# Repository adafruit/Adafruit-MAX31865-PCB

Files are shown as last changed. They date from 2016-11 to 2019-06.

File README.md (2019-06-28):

## Adafruit MAX31865 PCB

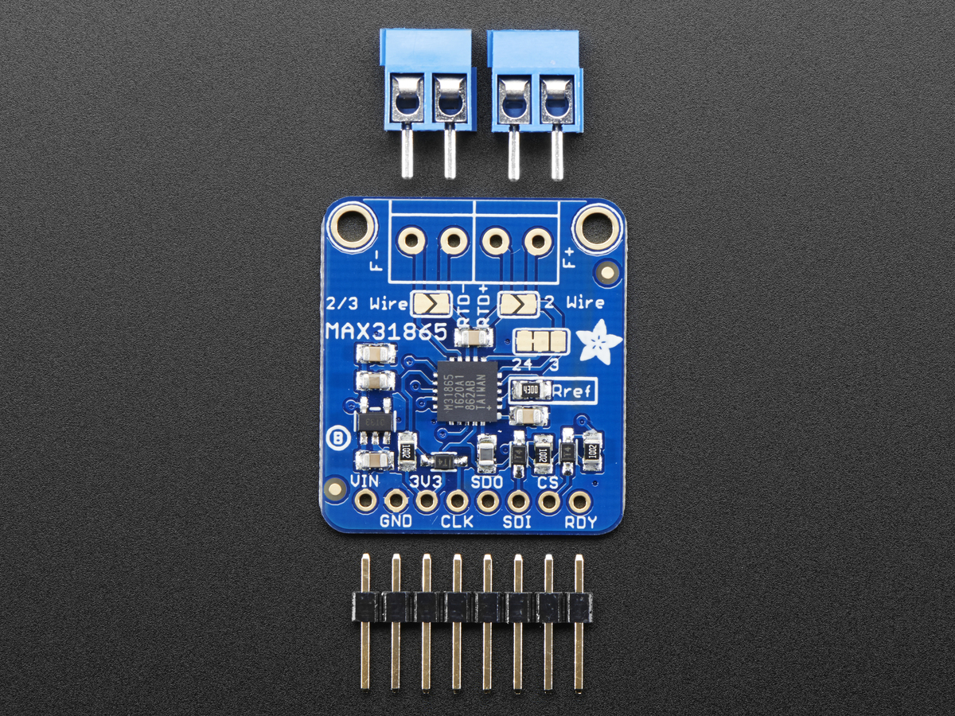
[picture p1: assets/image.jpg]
<a href="http://www.adafruit.com/products/3328"><br/>
Click here to purchase one from the Adafruit shop</a>

PCB files for the Adafruit MAX31865 RTD Sensor Breakout. Format is EagleCAD schematic and board layout
* https://www.adafruit.com/product/3328

### Description

For precision temperature sensing, nothing beats a Platinum RTD. Resistance temperature detectors (RTDs) are temperature sensors that contain a resistor that changes resistance value as its temperature changes, basically a kind of thermistor. In this sensor, the resistor is actually a small strip of Platinum with a resistance of 100 ohms at 0°C, thus the name PT100. Compared to most NTC/PTC thermistors, the PT type of RTD is much most stable and precise (but also more expensive) PT100's have been used for many years to measure temperature in laboratory and industrial processes, and have developed a reputation for accuracy (better than thermocouples), repeatability, and stability. 

However, to get that precision and accuracy out of your PT100 RTD you must use an amplifier that is designed to read the low resistance. Better yet, have an amplifier that can automatically adjust and compensate for the resistance of the connecting wires. If you're looking for a great RTD sensor, today is your lucky day because we have a lovely Adafruit RTD Sensor Amplifier with the MAX31865 breakout for use with any 2, 3 or 4 wire PT100 RTD!

### License

Adafruit invests time and resources providing this open source design, please support Adafruit and open-source hardware by purchasing products from [Adafruit](https://www.adafruit.com)!

Designed by Limor Fried/Ladyada for Adafruit Industries.

Creative Commons Attribution/Share-Alike, all text above must be included in any redistribution. See license.txt for additional details.

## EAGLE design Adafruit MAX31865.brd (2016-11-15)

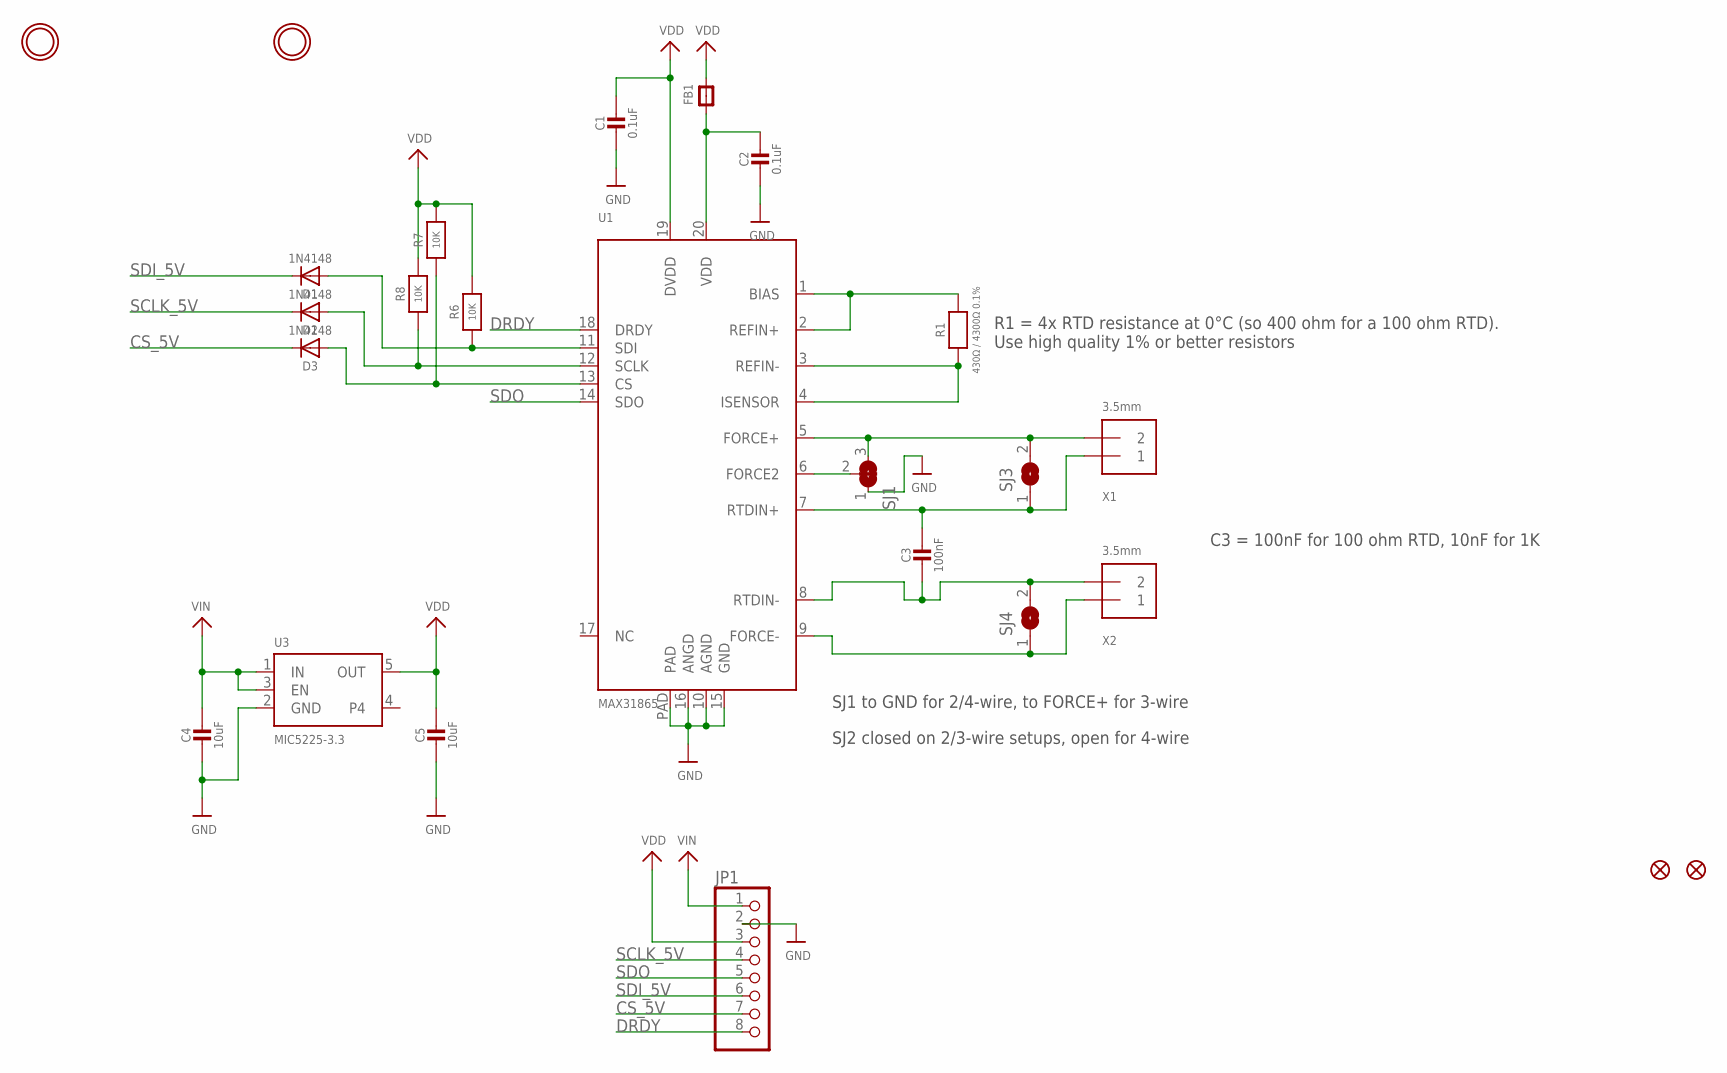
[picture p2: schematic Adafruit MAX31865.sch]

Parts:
C1, C2: 0.1uF; 0805-NO
C3: 100nF; 0805-NO
C4, C5: 10uF; 0805-NO
D1, D2, D3: 1N4148; SOD-323
FB1: FERRITE-0805NO; 0805-NO
FID1, FID2: FIDUCIAL""; FIDUCIAL_1MM
JP1: HEADER-1X870MIL; 1X08_ROUND_70
R1: 430Ω / 4300Ω 0.1%; 0805-NO
R6, R7, R8: 10K; 0805-NO
SJ1: SOLDERJUMPER_2WAY; SOLDERJUMPER_2WAY_OPEN_NOPASTE
SJ3, SJ4: SOLDERJUMPER; SOLDERJUMPER_ARROW_NOPASTE
U1: MAX31865; QFN20_4MM_0.65MM
U3: MIC5225-3.3; SOT23-5
U$18, U$19: MOUNTINGHOLE2.5; MOUNTINGHOLE_2.5_PLATED
X1, X2: 3.5mm; TERMBLOCK_1X2-3.5MM

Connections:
CS_5V: D3.C, JP1.7
DRDY: JP1.8, U1.18 (DRDY)
FORCE+: SJ1.3, SJ3.2, U1.5 (FORCE+), X1.2
FORCE-: SJ4.1, U1.9 (FORCE-), X2.1
GND: C1.2, C2.2, C4.2, C5.2, JP1.2, SJ1.1, U1.10 (AGND), U1.15 (GND), U1.16 (ANGD), U1.PAD, U3.2 (GND)
unnamed: R1.1, U1.3 (REFIN-), U1.4 (ISENSOR)
unnamed: R1.2, U1.1 (BIAS), U1.2 (REFIN+)
unnamed: C2.1, FB1.1, U1.20 (VDD)
unnamed: SJ1.2, U1.6 (FORCE2)
unnamed: D3.A, R7.1, U1.13 (CS)
unnamed: D2.A, R8.1, U1.12 (SCLK)
unnamed: D1.A, R6.1, U1.11 (SDI)
RTDIN+: C3.1, SJ3.1, U1.7 (RTDIN+), X1.1
RTDIN-: C3.2, SJ4.2, U1.8 (RTDIN-), X2.2
SCLK_5V: D2.C, JP1.4
SDI_5V: D1.C, JP1.6
SDO: JP1.5, U1.14 (SDO)
VDD: C1.1, C5.1, FB1.2, JP1.3, R6.2, R7.2, R8.2, U1.19 (DVDD), U3.5 (OUT)
VIN: C4.1, JP1.1, U3.1 (IN), U3.3 (EN)

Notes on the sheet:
C3 = 100nF for 100 ohm RTD, 10nF for 1K
R1 = 4x RTD resistance at 0°C (so 400 ohm for a 100 ohm RTD). Use high quality 1% or better resistors
SJ1 to GND for 2/4-wire, to FORCE+ for 3-wire
SJ2 closed on 2/3-wire setups, open for 4-wire

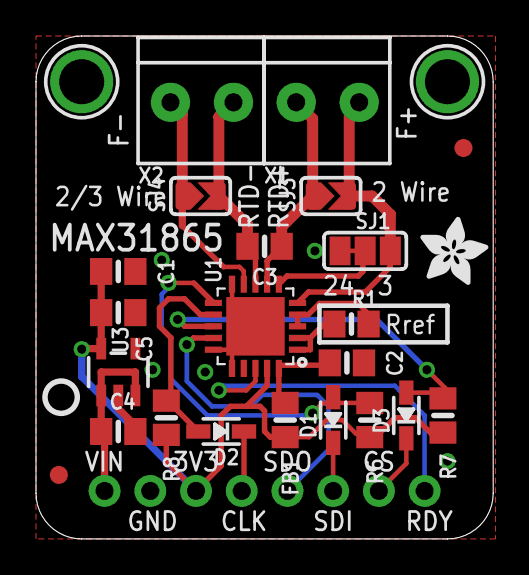
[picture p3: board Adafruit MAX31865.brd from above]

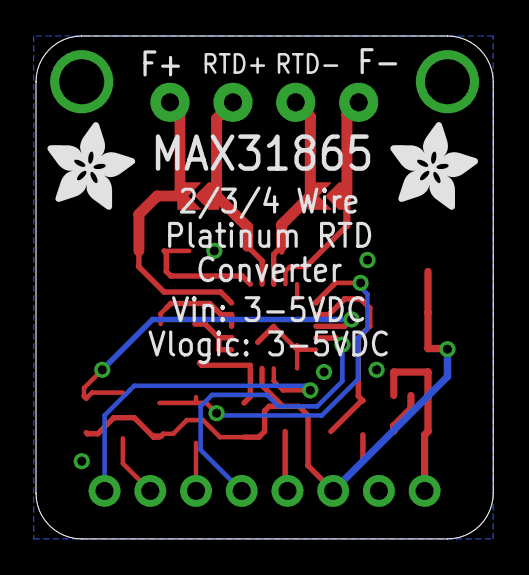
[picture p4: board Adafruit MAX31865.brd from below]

Board: 2 copper layers, 25.4 x 27.9 mm, 29 parts (2 on the bottom side), 19 nets.

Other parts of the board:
U$8: PCBFEAT-REV-040
U$16: ADAFRUIT_3.5MM
U$20, U$21: ADAFRUIT_5MM

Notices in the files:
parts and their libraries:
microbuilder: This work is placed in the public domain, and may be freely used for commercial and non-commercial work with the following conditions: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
